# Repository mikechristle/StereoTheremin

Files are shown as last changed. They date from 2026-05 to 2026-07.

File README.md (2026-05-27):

# StereoTheremin
II'm sure you are familiar with the Theremin. 
It is a musical instrument that uses hand movements to control pitch and volume. 
One hand controls pitch, and the other hand control volume. 
I like the expressiveness of a no contact instrument,
 but controlling two variables is just too limiting. 
 With my version each hand controls both pitch and volume. 
 The up/down motion controls volume, and the right/left motion controls pitch. 
 This way the right hand plays treble and the left hand plays base, like a piano.
## Code
The micropython code that runs on the Raspberry PI Pico.
## Control
The python code that runs on a PC or a tablet to control the Stereo Theremin.
## PCB
The KiCad files for the printed circuit board. 
Version 10.0.

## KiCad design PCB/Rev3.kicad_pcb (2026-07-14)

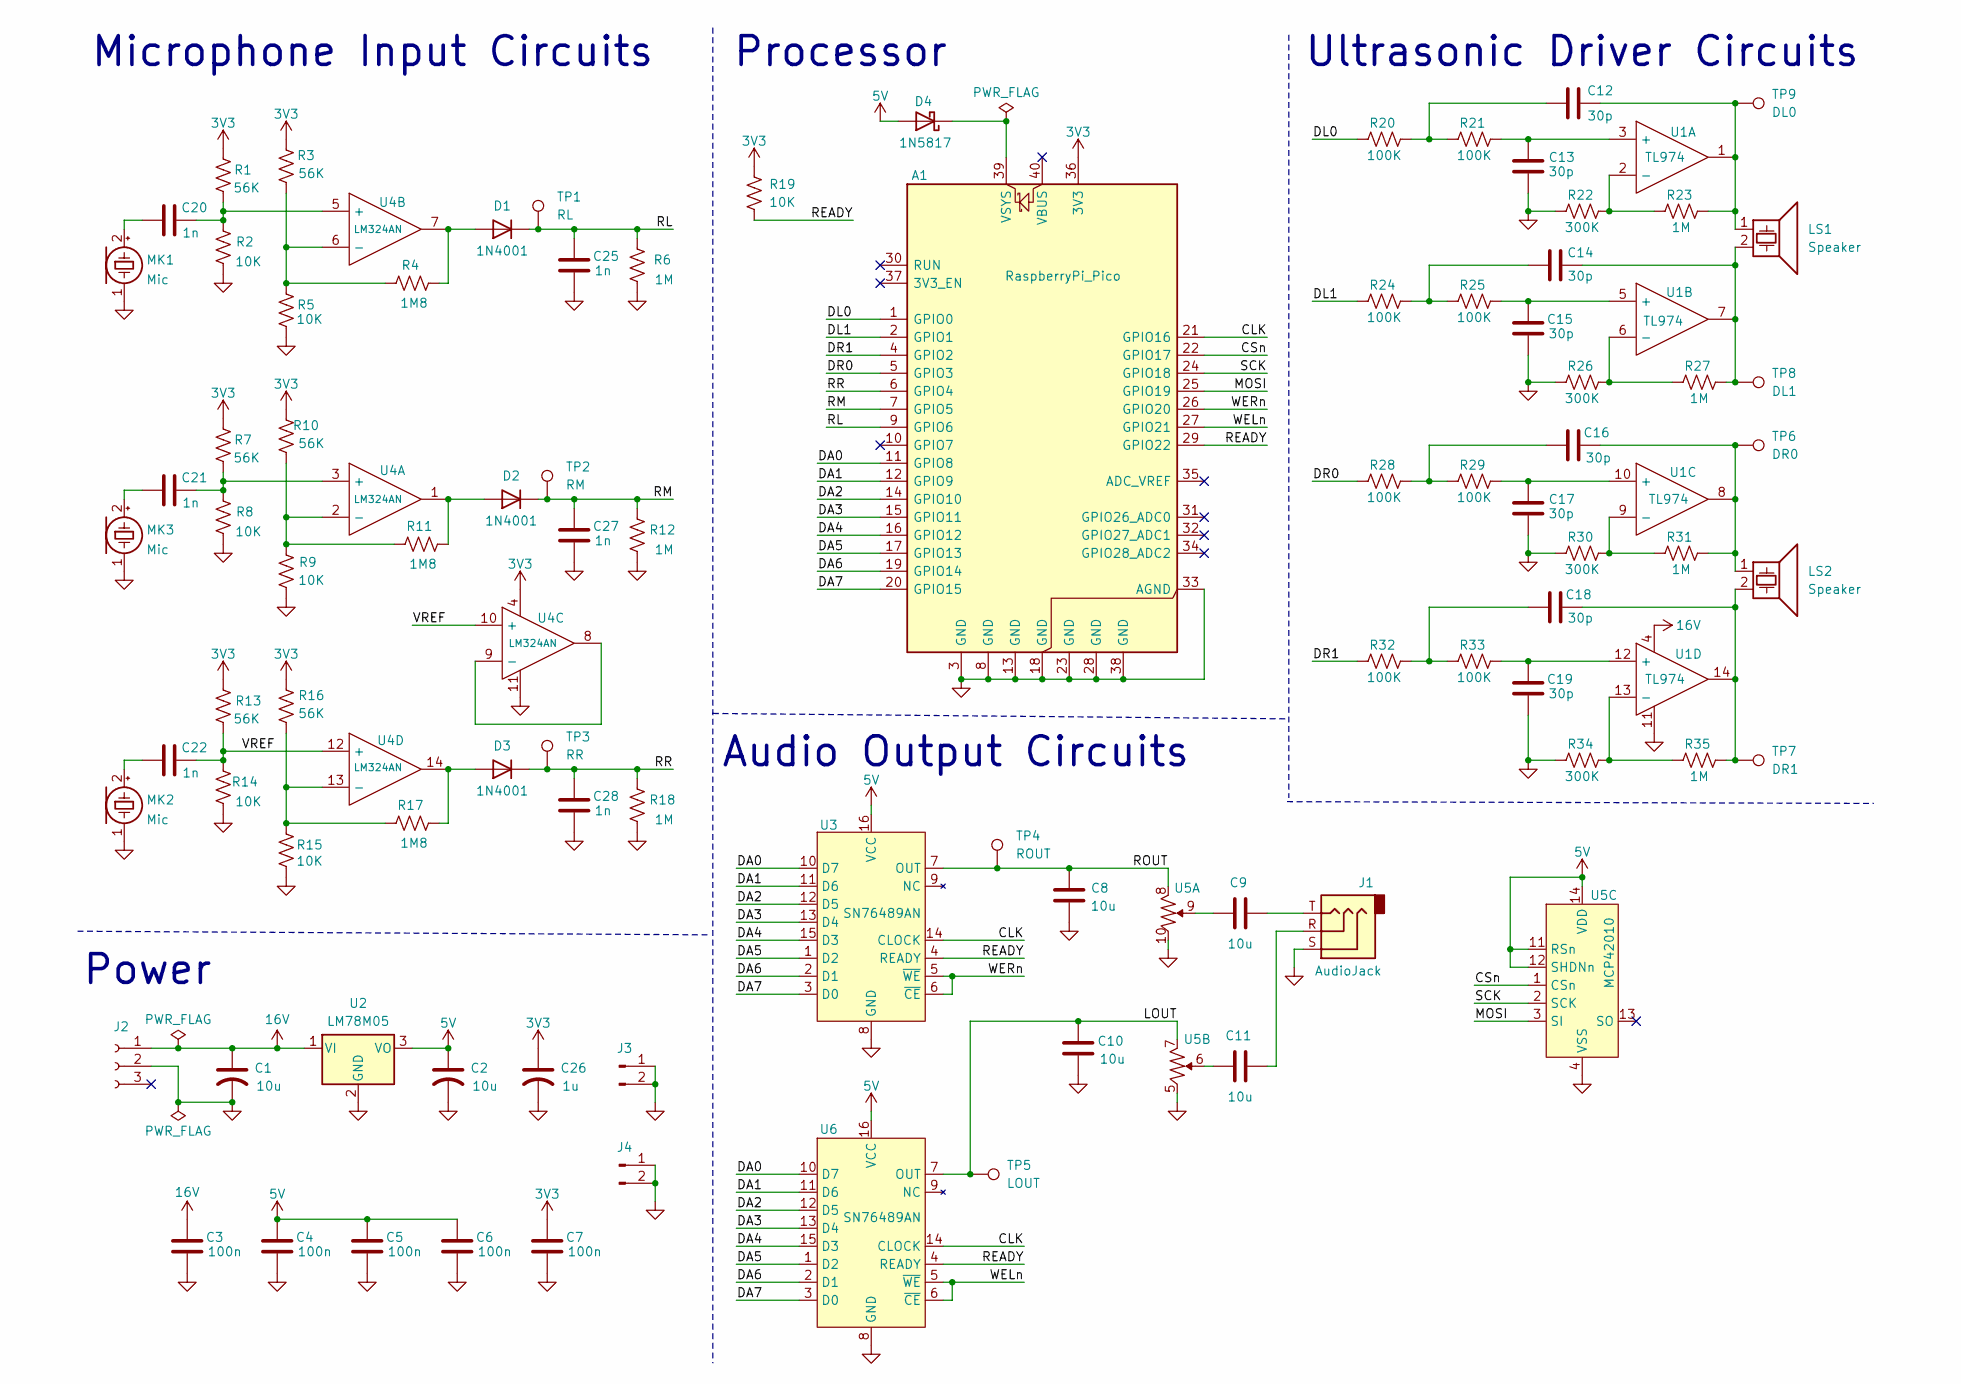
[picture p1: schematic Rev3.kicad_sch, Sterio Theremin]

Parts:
A1: RaspberryPi_Pico; RaspberryPi_Pico_Common_THT
C1, C2: 10u; CP_Radial_D6.3mm_P2.50mm
C3, C4, C5, C6, C7: 100n; C_Disc_D3.0mm_W1.6mm_P2.50mm
C8, C9, C10, C11: 10u; C_Disc_D4.3mm_W1.9mm_P5.00mm
C12, C13, C14, C15, C16, C17, C18, C19: 30p; C_Disc_D4.3mm_W1.9mm_P5.00mm
C20, C21, C22, C25, C27, C28: 1n; C_Disc_D4.3mm_W1.9mm_P5.00mm
C26: 1u; CP_Radial_D5.0mm_P2.50mm
D1, D2, D3: 1N4001; D_A-405_P7.62mm_Horizontal
D4: 1N5817; D_A-405_P7.62mm_Horizontal
J1: AudioJack; STX-3000
J2: Conn_01x03_Socket; BarrelJack_Kycon_KLDX-0202-xC_Horizontal
J3, J4: Conn_01x02_Pin; PinHeader_1x02_P2.54mm_Vertical
LS1, LS2: Speaker; Ultra Sonic TR
MK1, MK2, MK3: Mic; Ultra Sonic TR
R1, R3, R7, R10, R13, R16: 56K; R_Axial_DIN0204_L3.6mm_D1.6mm_P5.08mm_Horizontal
R2, R5, R8, R9, R14, R15, R19: 10K; R_Axial_DIN0204_L3.6mm_D1.6mm_P5.08mm_Horizontal
R4, R11, R17: 1M8; R_Axial_DIN0204_L3.6mm_D1.6mm_P5.08mm_Horizontal
R6, R12, R18, R23, R27, R31, R35: 1M; R_Axial_DIN0204_L3.6mm_D1.6mm_P5.08mm_Horizontal
R20, R21, R24, R25, R28, R29, R32, R33: 100K; R_Axial_DIN0204_L3.6mm_D1.6mm_P5.08mm_Horizontal
R22, R26, R30, R34: 300K; R_Axial_DIN0204_L3.6mm_D1.6mm_P5.08mm_Horizontal
TP1: RL; TestPoint_Loop_D2.50mm_Drill1.85mm
TP2: RM; TestPoint_Loop_D2.50mm_Drill1.85mm
TP3: RR; TestPoint_Loop_D2.50mm_Drill1.85mm
TP4: ROUT; TestPoint_Loop_D2.50mm_Drill1.85mm
TP5: LOUT; TestPoint_Loop_D2.50mm_Drill1.85mm
TP6: DR0; TestPoint_Loop_D2.50mm_Drill1.85mm
TP7: DR1; TestPoint_Loop_D2.50mm_Drill1.85mm
TP8: DL1; TestPoint_Loop_D2.50mm_Drill1.85mm
TP9: DL0; TestPoint_Loop_D2.50mm_Drill1.85mm
U1: TL974; DIP-14_W7.62mm
U2: LM78M05; TO-252-2
U3, U6: SN76489AN; DIP-16_W7.62mm
U4: LM324AN; DIP-14_W7.62mm
U5: MCP42010; DIP-14_W7.62mm

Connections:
3V3: A1.36 (3V3), C7.1, C26.1, R1.2, R3.2, R7.2, R10.2, R13.2, R16.2, R19.1, U4.4
5V: C2.1, C4.1, C5.1, C6.1, D4.2 (A), U2.3 (VO), U3.16 (VCC), U5.11 (RSn), U5.12 (SHDNn), U5.14 (VDD), U6.16 (VCC)
16V: C1.1, C3.1, J2.1, U1.4, U2.1 (VI)
/CLK: A1.21 (GPIO16), U3.14 (CLOCK), U6.14 (CLOCK)
/CSn: A1.22 (GPIO17), U5.1 (CSn)
/DA0: A1.11 (GPIO8), U3.10 (D7), U6.10 (D7)
/DA1: A1.12 (GPIO9), U3.11 (D6), U6.11 (D6)
/DA2: A1.14 (GPIO10), U3.12 (D5), U6.12 (D5)
/DA3: A1.15 (GPIO11), U3.13 (D4), U6.13 (D4)
/DA4: A1.16 (GPIO12), U3.15 (D3), U6.15 (D3)
/DA5: A1.17 (GPIO13), U3.1 (D2), U6.1 (D2)
/DA6: A1.19 (GPIO14), U3.2 (D1), U6.2 (D1)
/DA7: A1.20 (GPIO15), U3.3 (D0), U6.3 (D0)
/DL0: A1.1 (GPIO0), R20.1
/DL1: A1.2 (GPIO1), R24.1
/DR0: A1.5 (GPIO3), R28.1
/DR1: A1.4 (GPIO2), R32.1
/LOUT: C10.2, TP5.1 (1_1), U5.7, U6.7 (OUT)
/MOSI: A1.25 (GPIO19), U5.3 (SI)
/READY: A1.29 (GPIO22), R19.2, U3.4 (READY), U6.4 (READY)
/RL: A1.9 (GPIO6), C25.1, D1.1 (K), R6.2, TP1.1 (1_1)
/RM: A1.7 (GPIO5), C27.1, D2.1 (K), R12.2, TP2.1 (1_1)
/ROUT: C8.2, TP4.1 (1_1), U3.7 (OUT), U5.8
/RR: A1.6 (GPIO4), C28.1, D3.1 (K), R18.2, TP3.1 (1_1)
/SCK: A1.24 (GPIO18), U5.2 (SCK)
/VREF: C22.2, R13.1, R14.2, U4.10 (+), U4.12 (+)
/WELn: A1.27 (GPIO21), U6.5 (~WE), U6.6 (~CE)
/WERn: A1.26 (GPIO20), U3.5 (~WE), U3.6 (~CE)
GND: A1.3 (GND), A1.8 (GND), A1.13 (GND), A1.18 (GND), A1.23 (GND), A1.28 (GND), A1.33 (AGND), A1.38 (GND), C1.2, C2.2, C3.2, C4.2, C5.2, C6.2, C7.2, C8.1, C10.1, C13.2, C15.2, C17.2, C19.2, C25.2, C26.2, C27.2, C28.2, J1.S, J2.2, J3.1, J3.2, J4.1, J4.2, MK1.1 (-), MK2.1 (-), MK3.1 (-), R2.1, R5.2, R6.1, R8.1, R9.2, R12.1, R14.1, R15.2, R18.1, R22.1, R26.1, R30.1, R34.1, U1.11, U2.2 (GND), U3.8 (GND), U4.11, U5.4 (VSS), U5.5, U5.10, U6.8 (GND)
unnamed: A1.39 (VSYS), D4.1 (K)
unnamed: C9.1, J1.T
unnamed: C9.2, U5.9
unnamed: C11.1, J1.R
unnamed: C11.2, U5.6
unnamed: C12.1, R20.2, R21.1
unnamed: C12.2, LS1.1, R23.2, TP9.1 (1_1), U1.1
unnamed: C14.1, R24.2, R25.1
unnamed: C14.2, LS1.2, R27.2, TP8.1 (1_1), U1.7
unnamed: C16.1, R28.2, R29.1
unnamed: C16.2, LS2.1, R31.2, TP6.1 (1_1), U1.8
unnamed: C18.1, R32.2, R33.1
unnamed: C18.2, LS2.2, R35.2, TP7.1 (1_1), U1.14
unnamed: D1.2 (A), R4.2, U4.7
unnamed: D2.2 (A), R11.2, U4.1
unnamed: D3.2 (A), R17.2, U4.14
unnamed: C20.1, MK1.2 (+)
unnamed: C22.1, MK2.2 (+)
unnamed: C21.1, MK3.2 (+)
unnamed: C13.1, R21.2, U1.3 (+)
unnamed: R22.2, R23.1, U1.2 (-)
unnamed: C15.1, R25.2, U1.5 (+)
unnamed: R26.2, R27.1, U1.6 (-)
unnamed: C17.1, R29.2, U1.10 (+)
unnamed: R30.2, R31.1, U1.9 (-)
unnamed: C19.1, R33.2, U1.12 (+)
unnamed: R34.2, R35.1, U1.13 (-)
unnamed: C21.2, R7.1, R8.2, U4.3 (+)
unnamed: R9.1, R10.1, R11.1, U4.2 (-)
unnamed: C20.2, R1.1, R2.2, U4.5 (+)
unnamed: R3.1, R4.1, R5.1, U4.6 (-)
unnamed: U4.8, U4.9 (-)
unnamed: R15.1, R16.1, R17.1, U4.13 (-)

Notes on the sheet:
Audio Output Circuits
Processor
Power
Microphone Input Circuits
Ultrasonic Driver Circuits

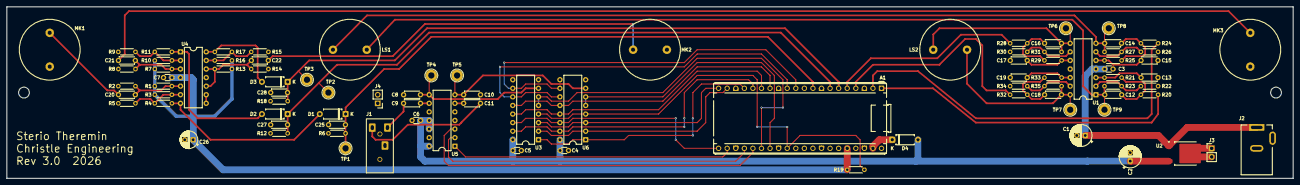
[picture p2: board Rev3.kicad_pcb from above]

Board: 2 copper layers, 381.0 x 50.8 mm, 90 parts (0 on the bottom side), 62 nets.

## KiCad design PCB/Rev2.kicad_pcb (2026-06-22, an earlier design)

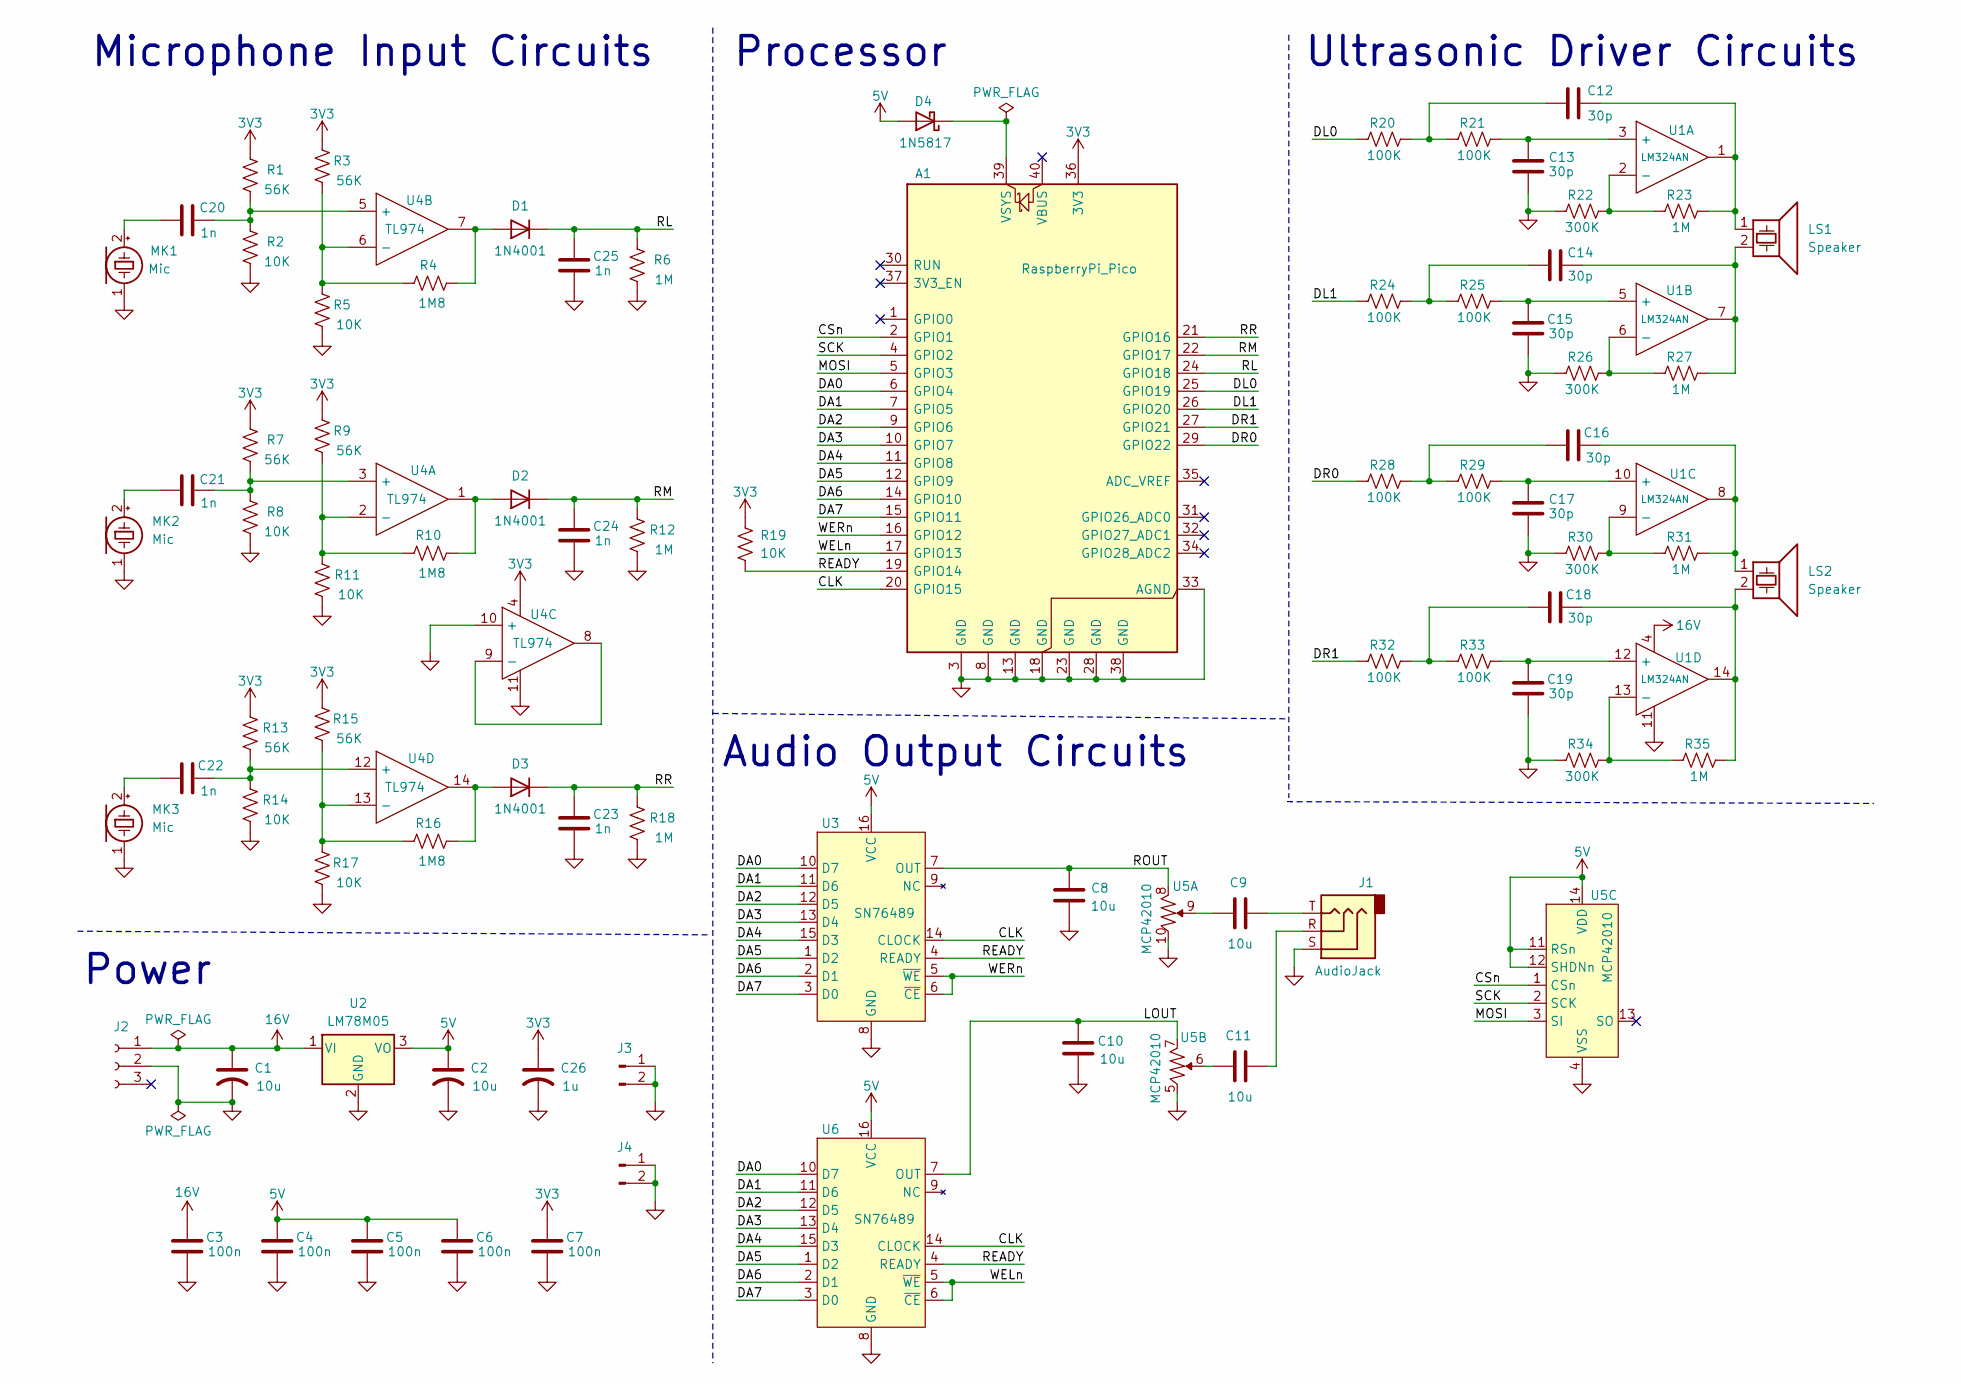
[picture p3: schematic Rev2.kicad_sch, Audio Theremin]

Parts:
A1: RaspberryPi_Pico; RaspberryPi_Pico_Common_THT
C1, C2: 10u; CP_Radial_D6.3mm_P2.50mm
C3, C4, C5, C6, C7: 100n; C_Disc_D3.0mm_W1.6mm_P2.50mm
C8, C9, C10, C11: 10u; C_Disc_D4.3mm_W1.9mm_P5.00mm
C12, C13, C14, C15, C16, C17, C18, C19: 30p; C_Disc_D4.3mm_W1.9mm_P5.00mm
C20, C21, C22, C23, C24, C25: 1n; C_Disc_D4.3mm_W1.9mm_P5.00mm
C26: 1u; CP_Radial_D5.0mm_P2.50mm
D1, D2, D3: 1N4001; D_DO-41_SOD81_P10.16mm_Horizontal
D4: 1N5817; D_DO-41_SOD81_P10.16mm_Horizontal
J1: AudioJack; STX-3000
J2: Conn_01x03_Socket; BarrelJack_Kycon_KLDX-0202-xC_Horizontal
J3, J4: Conn_01x02_Pin; PinHeader_1x02_P2.54mm_Vertical
LS1, LS2: Speaker; PinHeader_1x02_P2.54mm_Vertical
MK1, MK2, MK3: Mic; PinHeader_1x02_P2.54mm_Vertical
R1, R3, R7, R9, R13, R15: 56K; R_Axial_DIN0204_L3.6mm_D1.6mm_P5.08mm_Horizontal
R2, R5, R8, R11, R14, R17, R19: 10K; R_Axial_DIN0204_L3.6mm_D1.6mm_P5.08mm_Horizontal
R4, R10, R16: 1M8; R_Axial_DIN0204_L3.6mm_D1.6mm_P5.08mm_Horizontal
R6, R12, R18, R23, R27, R31, R35: 1M; R_Axial_DIN0204_L3.6mm_D1.6mm_P5.08mm_Horizontal
R20, R21, R24, R25, R28, R29, R32, R33: 100K; R_Axial_DIN0204_L3.6mm_D1.6mm_P5.08mm_Horizontal
R22, R26, R30, R34: 300K; R_Axial_DIN0204_L3.6mm_D1.6mm_P5.08mm_Horizontal
U1: LM324AN; DIP-14_W7.62mm
U2: LM78M05; TO-252-2
U3, U6: SN76489; DIP-16_W7.62mm
U4: TL974; DIP-14_W7.62mm
U5: MCP42010; DIP-14_W7.62mm

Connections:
3V3: A1.36 (3V3), C7.1, C26.1, R1.2, R3.2, R7.2, R9.2, R13.2, R15.2, R19.1, U4.4
5V: C2.1, C4.1, C5.1, C6.1, D4.2 (A), U2.3 (VO), U3.16 (VCC), U5.11 (RSn), U5.12 (SHDNn), U5.14 (VDD), U6.16 (VCC)
16V: C1.1, C3.1, J2.1, U1.4, U2.1 (VI)
/CLK: A1.20 (GPIO15), U3.14 (CLOCK), U6.14 (CLOCK)
/CSn: A1.2 (GPIO1), U5.1 (CSn)
/DA0: A1.6 (GPIO4), U3.10 (D7), U6.10 (D7)
/DA1: A1.7 (GPIO5), U3.11 (D6), U6.11 (D6)
/DA2: A1.9 (GPIO6), U3.12 (D5), U6.12 (D5)
/DA3: A1.10 (GPIO7), U3.13 (D4), U6.13 (D4)
/DA4: A1.11 (GPIO8), U3.15 (D3), U6.15 (D3)
/DA5: A1.12 (GPIO9), U3.1 (D2), U6.1 (D2)
/DA6: A1.14 (GPIO10), U3.2 (D1), U6.2 (D1)
/DA7: A1.15 (GPIO11), U3.3 (D0), U6.3 (D0)
/DL0: A1.25 (GPIO19), R20.1
/DL1: A1.26 (GPIO20), R24.1
/DR0: A1.29 (GPIO22), R28.1
/DR1: A1.27 (GPIO21), R32.1
/LOUT: C10.2, U5.7, U6.7 (OUT)
/MOSI: A1.5 (GPIO3), U5.3 (SI)
/READY: A1.19 (GPIO14), R19.2, U3.4 (READY), U6.4 (READY)
/RL: A1.24 (GPIO18), C25.1, D1.1 (K), R6.2
/RM: A1.22 (GPIO17), C24.1, D2.1 (K), R12.2
/ROUT: C8.2, U3.7 (OUT), U5.8
/RR: A1.21 (GPIO16), C23.1, D3.1 (K), R18.2
/SCK: A1.4 (GPIO2), U5.2 (SCK)
/WELn: A1.17 (GPIO13), U6.5 (~WE), U6.6 (~CE)
/WERn: A1.16 (GPIO12), U3.5 (~WE), U3.6 (~CE)
GND: A1.3 (GND), A1.8 (GND), A1.13 (GND), A1.18 (GND), A1.23 (GND), A1.28 (GND), A1.33 (AGND), A1.38 (GND), C1.2, C2.2, C3.2, C4.2, C5.2, C6.2, C7.2, C8.1, C10.1, C13.2, C15.2, C17.2, C19.2, C23.2, C24.2, C25.2, C26.2, J1.S, J2.2, J3.1, J3.2, J4.1, J4.2, MK1.1 (-), MK2.1 (-), MK3.1 (-), R2.1, R5.1, R6.1, R8.1, R11.1, R12.1, R14.1, R17.1, R18.1, R22.1, R26.1, R30.1, R34.1, U1.11, U2.2 (GND), U3.8 (GND), U4.10 (+), U4.11, U5.4 (VSS), U5.5, U5.10, U6.8 (GND)
unnamed: A1.39 (VSYS), D4.1 (K)
unnamed: C9.1, J1.T
unnamed: C9.2, U5.9
unnamed: C11.1, J1.R
unnamed: C11.2, U5.6
unnamed: C12.1, R20.2, R21.1
unnamed: C12.2, LS1.1, R23.2, U1.1
unnamed: C14.1, R24.2, R25.1
unnamed: C14.2, LS1.2, R27.2, U1.7
unnamed: C16.1, R28.2, R29.1
unnamed: C16.2, LS2.1, R31.2, U1.8
unnamed: C18.1, R32.2, R33.1
unnamed: C18.2, LS2.2, R35.2, U1.14
unnamed: D1.2 (A), R4.2, U4.7
unnamed: D2.2 (A), R10.2, U4.1
unnamed: D3.2 (A), R16.2, U4.14
unnamed: C20.1, MK1.2 (+)
unnamed: C21.1, MK2.2 (+)
unnamed: C22.1, MK3.2 (+)
unnamed: C13.1, R21.2, U1.3 (+)
unnamed: R22.2, R23.1, U1.2 (-)
unnamed: C15.1, R25.2, U1.5 (+)
unnamed: R26.2, R27.1, U1.6 (-)
unnamed: C17.1, R29.2, U1.10 (+)
unnamed: R30.2, R31.1, U1.9 (-)
unnamed: C19.1, R33.2, U1.12 (+)
unnamed: R34.2, R35.1, U1.13 (-)
unnamed: C21.2, R7.1, R8.2, U4.3 (+)
unnamed: R9.1, R10.1, R11.2, U4.2 (-)
unnamed: C20.2, R1.1, R2.2, U4.5 (+)
unnamed: R3.1, R4.1, R5.2, U4.6 (-)
unnamed: U4.8, U4.9 (-)
unnamed: C22.2, R13.1, R14.2, U4.12 (+)
unnamed: R15.1, R16.1, R17.2, U4.13 (-)

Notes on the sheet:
Audio Output Circuits
Processor
Power
Microphone Input Circuits
Ultrasonic Driver Circuits

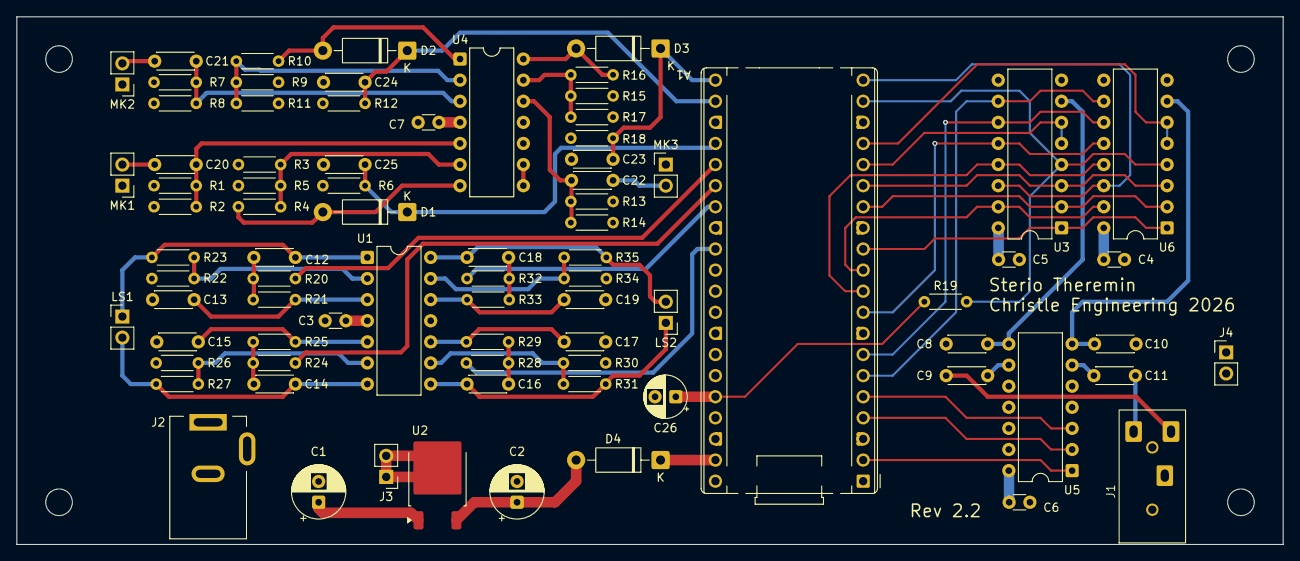
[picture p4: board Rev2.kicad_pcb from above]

Board: 4 copper layers, 152.4 x 63.5 mm, 85 parts (0 on the bottom side), 62 nets.

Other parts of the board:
MH1, MH2, MH3, MH4: MountingHole_3.2mm_M3

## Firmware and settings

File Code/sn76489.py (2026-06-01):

# -------------------------------------------------------------------------
# SN76489 Sound Generator PIO Code
# Mike Christle 2026
#
# Pin order:
# D0, D1, D2, D3, D4, D5, D6, D7, WER, WEL, READY, CLK
# -------------------------------------------------------------------------
from machine import Pin, PWM
import rp2


CLK_FREQ = 654_720


class SN76489:
    def __init__(self, smn, pin):
        '''
        Driver for the SN76489 audio generator chips.
        smn    State machine number.
        pin    GPIO number of the first pin.
        '''
        self.d7 = Pin(pin,     Pin.OUT)
        self.d6 = Pin(pin + 1, Pin.OUT)
        self.d5 = Pin(pin + 2, Pin.OUT)
        self.d4 = Pin(pin + 3, Pin.OUT)
        self.d3 = Pin(pin + 4, Pin.OUT)
        self.d2 = Pin(pin + 5, Pin.OUT)
        self.d1 = Pin(pin + 6, Pin.OUT)
        self.d0 = Pin(pin + 7, Pin.OUT)

        self.wel = Pin(pin +  8, Pin.OUT, value=1) # WEn & CEn
        self.wer = Pin(pin +  9, Pin.OUT, value=1) # WEn & CEn
        self.rdy = Pin(pin + 10, Pin.IN)

        self.clk = Pin(pin + 11, Pin.OUT)
        self.clk_pwm = PWM(self.clk,
                           freq=CLK_FREQ,
                           duty_u16=32_768)
#         freq = self.clk_pwm.freq()
#         print(freq)

        self.sm = rp2.StateMachine(
            smn,
            self.sm_code,
            freq=10_000_000,
            out_base=self.d7,
            set_base=self.wel,
            jmp_pin=self.rdy,
            )
        self.sm.active(1)

        # Turn off all outputs
        self.write_reg(0, 1, 0x0F)
        self.write_reg(0, 3, 0x0F)
        self.write_reg(0, 5, 0x0F)
        self.write_reg(0, 7, 0x0F)
        self.write_reg(1, 1, 0x0F)
        self.write_reg(1, 3, 0x0F)
        self.write_reg(1, 5, 0x0F)
        self.write_reg(1, 7, 0x0F)

        self.factors = [[0.0, 0.0], [0.0, 0.0]]
        self.attens = [[15, 15], [15, 15]]

    # ---------------------------------------------------------------------
    def set_factor(self, chip, chan, data):
        '''
        Set the frequency factor for a voice.
        chip    Chip number, 0 or 1.
        chan    Channel number, 2 or 3.
        data    Factor value.
        '''

        if chip < 0 or chip > 1:
            raise ValueError('Chip out of range, 0, 1.')

        if chan < 2 or chan > 3:
            raise ValueError('Channel number out of range, 2 or 3.')

        
        self.factors[chip][chan - 2] = data

    # ---------------------------------------------------------------------
    def set_atten(self, chip, chan, data):
        '''
        Set the attenuation for a voice.
        chip    Chip number, 0 or 1.
        chan    Channel number, 2 or 3.
        data    Attenuation value.
        '''

        if chip < 0 or chip > 1:
            raise ValueError('Chip out of range, 0, 1.')

        if chan < 2 or chan > 3:
            raise ValueError('Channel number out of range, 2 or 3.')

        
        self.attens[chip][chan - 2] = data

    # ---------------------------------------------------------------------
    def write_reg(self, chip, adrs, data):
        '''
        Write value to a register.
        chip    Chip number, 0 or 1.
        adrs    Address to write, 0 to 7.
        data    Data value.
        '''

        value = (chip << 8) | 0x80 | (adrs << 4) | (data & 0x0F)
        # print(f'value 1 {value:08X}')
        self.sm.put(value)
        if adrs == 0 or adrs == 2 or adrs == 4:
            value = (chip << 8) | (data >> 4)
            # print(f'value 2 {value:08X}')
            self.sm.put(value)

    # ---------------------------------------------------------------------
    def write_freq(self, chip, chan, freq):
        '''
        chip   Chip to write.     0, 1
        chan   Channel to write.  0, 1, 2
        freq   Frequency.         20 to 20K Hz
               
        '''

        if chip < 0 or chip > 1:
            raise ValueError('Chip out of range, 0, 1.')

        if chan < 0 or chan > 2:
            raise ValueError('Channel out of range, 0, 1, 2.')

        if freq < 20 or freq > 20_000:
            raise ValueError('Frequency out of range, 20 to 20K Hz.')

        freq = int(CLK_FREQ / 32 / freq)
        adrs = chan * 2
        self.write_reg(chip, adrs, freq)

    # ---------------------------------------------------------------------
    def write_attn(self, chip, chan, attn):
        '''
        chip   Chip to write.     0, 1
        chan   Channel to write.  0, 1, 2
        attn   Attenuation.       0 to 30 db in 2db increments
               
        '''

        if chip < 0 or chip > 1:
            raise ValueError('Chip out of range, 0, 1.')

        if chan < 0 or chan > 2:
            raise ValueError('Channel out of range, 0, 1, 2.')

        if attn < 0 or attn > 30:
            raise ValueError('Attenuation out of range, 0 to 30 db.')

        attn //= 2
        adrs = chan * 2
        self.write_reg(chip, adrs + 1, attn)

    # ---------------------------------------------------------------------
    def update(chip, freq):
        '''
        Update the frequency and attenuation for a channel.
        chip    Chip number, 0 or 1.
        freq    Frequency for voice 1.
        '''

        write_freq(chip, 0, freq)
        write_freq(chip, 1, freq * self.factor[chip][0])
        write_freq(chip, 2, freq * self.factor[chip][1])

        write_attn(chip, 1, self.factor[chip][0])
        write_attn(chip, 2, self.factor[chip][1])

    # ---------------------------------------------------------------------
    @rp2.asm_pio(out_shiftdir=rp2.PIO.SHIFT_RIGHT,
                 fifo_join=rp2.PIO.JOIN_TX,
                 set_init=(rp2.PIO.OUT_HIGH, rp2.PIO.OUT_HIGH),
                 out_init=(rp2.PIO.OUT_LOW, rp2.PIO.OUT_LOW,
                           rp2.PIO.OUT_LOW, rp2.PIO.OUT_LOW,
                           rp2.PIO.OUT_LOW, rp2.PIO.OUT_LOW,
                           rp2.PIO.OUT_LOW, rp2.PIO.OUT_LOW))
    def sm_code():

        label('lbl0')
        set(pins, 3)        # Clear WE
        pull(block)         # Wait for nect command
        out(pins, 8)        # Output data byte
        out(y, 24)          # Which channel?
        jmp(not_y, 'lbl1')

        set(pins, 1)        # Assert WERn
        jmp('lbl2')

        label('lbl1')
        set(pins, 2) [1]    # Assert WELn

        label('lbl2')
        jmp(pin, 'lbl0')    # Wait for READY to go high
        jmp('lbl2')


# -------------------------------------------------------------------------
C0  = 7645  # 16.35 Hz
C0S = 7217  # 17.32 Hz
D0  = 6812  # 18.35 Hz
D0S = 6427  # 19.45 Hz
E0  = 6068  # 20.6 Hz
F0  = 5726  # 21.83 Hz
F0S = 5407  # 23.12 Hz
G0  = 5102  # 24.5 Hz
G0S = 4815  # 25.96 Hz
A0  = 4545  # 27.5 Hz
A0S = 4290  # 29.14 Hz
B0  = 4049  # 30.87 Hz
C1  = 3823  # 32.7 Hz
C1S = 3608  # 34.65 Hz
D1  = 3405  # 36.71 Hz
D1S = 3214  # 38.89 Hz
E1  = 3034  # 41.2 Hz
F1  = 2864  # 43.65 Hz
F1S = 2703  # 46.25 Hz
G1  = 2551  # 49.0 Hz
G1S = 2408  # 51.91 Hz
A1  = 2273  # 55.0 Hz
A1S = 2145  # 58.27 Hz
B1  = 2025  # 61.74 Hz
C2  = 1911  # 65.41 Hz
C2S = 1804  # 69.3 Hz
D2  = 1703  # 73.42 Hz
D2S = 1607  # 77.78 Hz
E2  = 1517  # 82.41 Hz
F2  = 1432  # 87.31 Hz
F2S = 1351  # 92.5 Hz
G2  = 1276  # 98.0 Hz
G2S = 1204  # 103.83 Hz
A2  = 1136  # 110.0 Hz
A2S = 1073  # 116.54 Hz
B2  = 1012  # 123.47 Hz
C3  =  956  # 130.81 Hz
C3S =  902  # 138.59 Hz
D3  =  851  # 146.83 Hz
D3S =  804  # 155.56 Hz
E3  =  758  # 164.81 Hz
F3  =  716  # 174.61 Hz
F3S =  676  # 185.0 Hz
G3  =  638  # 196.0 Hz
G3S =  602  # 207.65 Hz
A3  =  568  # 220.0 Hz
A3S =  536  # 233.08 Hz
B3  =  506  # 246.94 Hz
C4  =  478  # 261.63 Hz
C4S =  451  # 277.18 Hz
D4  =  426  # 293.66 Hz
D4S =  402  # 311.13 Hz
E4  =  379  # 329.63 Hz
F4  =  358  # 349.23 Hz
F4S =  338  # 369.99 Hz
G4  =  319  # 392.0 Hz
G4S =  301  # 415.3 Hz
A4  =  284  # 440.0 Hz
A4S =  268  # 466.16 Hz
B4  =  253  # 493.88 Hz
C5  =  239  # 523.25 Hz
C5S =  225  # 554.37 Hz
D5  =  213  # 587.33 Hz
D5S =  201  # 622.25 Hz
E5  =  190  # 659.26 Hz
F5  =  179  # 698.46 Hz
F5S =  169  # 739.99 Hz
G5  =  159  # 783.99 Hz
G5S =  150  # 830.61 Hz
A5  =  142  # 880.0 Hz
A5S =  134  # 932.33 Hz
B5  =  127  # 987.77 Hz
C6  =  119  # 1046.5 Hz
C6S =  113  # 1108.73 Hz
D6  =  106  # 1174.66 Hz
D6S =  100  # 1244.51 Hz
E6  =   95  # 1318.51 Hz
F6  =   89  # 1396.91 Hz
F6S =   84  # 1479.98 Hz
G6  =   80  # 1567.98 Hz
G6S =   75  # 1661.22 Hz
A6  =   71  # 1760.0 Hz
A6S =   67  # 1864.66 Hz
B6  =   63  # 1975.53 Hz
C7  =   60  # 2093.0 Hz
C7S =   56  # 2217.46 Hz
D7  =   53  # 2349.32 Hz
D7S =   50  # 2489.02 Hz
E7  =   47  # 2637.02 Hz
F7  =   45  # 2793.83 Hz
F7S =   42  # 2959.96 Hz
G7  =   40  # 3135.96 Hz
G7S =   38  # 3322.44 Hz
A7  =   36  # 3520.0 Hz
A7S =   34  # 3729.31 Hz
B7  =   32  # 3951.07 Hz
C8  =   30  # 4186.01 Hz
C8S =   28  # 4434.92 Hz
D8  =   27  # 4698.64 Hz
D8S =   25  # 4978.03 Hz

# -------------------------------------------------------------------------
if __name__ == "__main__":

    from time import sleep

    MENU = (
    'x         Exit\n'
    'f n c v   Set chip n channel c to frequency v\n'
    'a n c v   Set chip n channel c to attenuation v\n'
    )

    sn = SN76489(0, 0)
    print(MENU)
    while True:
        cmd = input('> ').split()
        cnt = len(cmd)
        if cnt < 1:
            print(MENU)
        elif cmd[0] == 'x':
            break
        elif cnt != 4:
            continue
        elif cmd[0] == 'f':
            chip = int(cmd[1])
            chan = int(cmd[2])
            freq = int(cmd[3])
            sn.write_freq(chip, chan, freq)
        elif cmd[0] == 'a':
            chip = int(cmd[1])
            chan = int(cmd[2])
            attn = int(cmd[3])
            sn.write_attn(chip, chan, attn)

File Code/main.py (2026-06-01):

# -------------------------------------------------------------------------
# Ultrasonic Theremin
# Mike Christle Feb 2026
# -------------------------------------------------------------------------

from machine import Pin, SPI
from mcp42010 import MCP42010
from sn76489 import SN76489
from sequencer import Sequencer
from measure import Measure
from machine import reset


LEFT_FREQ_LO = 65.41
LEFT_FREQ_HI = 493.88
RIGHT_FREQ_LO = 130.81
RIGHT_FREQ_HI = 987.77


cntr = 0
# -------------------------------------------------------------------------
def process_left(_):
    global cntr

    ll = mll.get()
    lm = mlm.get()
    if trace_left:
        print(f'process_left {ll} {lm} {cntr}   \r', end='')
        cntr += 1

    if ll or lm < 0:
        return

    left_pitch = lm - ll
    left_volume = lm + ll
    pots.write(MCP42010.POT0, left_volume)


# -------------------------------------------------------------------------
def process_right(_):
    global cntr

    rm = mrm.get()
    rr = mrr.get()
    if trace_right:
        print(f'process_right {rm} {rr} {cntr}   \r', end='')
        cntr += 1

    if rm or rr < 0:
        return

    right_pitch = rr - rm
    right_volume = rr + rm
    pots.write(MCP42010.POT1, right_volume)


# -------------------------------------------------------------------------
# Setup pins
pin_dl0 = Pin(19, mode=Pin.OUT)
pin_dl1 = Pin(20, mode=Pin.OUT)
pin_dr0 = Pin(21, mode=Pin.OUT)
pin_dr1 = Pin(22, mode=Pin.OUT)

pin_rl = Pin(18, mode=Pin.IN)
pin_rm = Pin(17, mode=Pin.IN)
pin_rr = Pin(16, mode=Pin.IN)

# spi, cs_pin, clk_pin, tx_pin
pots = MCP42010(0, 1, 2, 3)

# smn, first_pin
audio = SN76489(7, 4)

# smn, tx_pin, rx_pin
mll = Measure(2, pin_dl0, pin_rl)
mlm = Measure(3, pin_dl0, pin_rm)
mrm = Measure(5, pin_dr0, pin_rm)
mrr = Measure(6, pin_dr0, pin_rr)

# right_cb, left_cb, pins
pins = 19, 18, 17, 16
seq = Sequencer(process_right, process_left, pin_dl0)

trace_left = False
trace_right = True

FACTORS = [
    1.0,          # P1
    1.0 + 1/12,   # m2
    1.0 + 2/12,   # M2
    1.0 + 3/12,   # m3
    1.0 + 4/12,   # M3
    1.0 + 5/12,   # P4
    1.0 + 6/12,   # a4
    1.0 + 7/12,   # P5
    1.0 + 8/12,   # m6
    1.0 + 9/12,   # M6
    1.0 + 10/12,  # m7
    1.0 + 11/12,  # M7
    2.0,          # P8
    2.0,          # 2X
    3.0,          # 3X
    4.0,          # 4X
    5.0,          # 5X
    6.0,          # 6X
    7.0,          # 7X
    8.0,          # 8X
    9.0,          # 9X
    ]


MENU = '''
x       Exit
tl      Enable trace mode for left side.
tr      Enable trace mode for right side.

L2F N   Set left voice 2 to frequency N.
L2A N   Set left voice 2 to attenuation N. 
L3F N   Set left voice 3 to frequency N.
L3A N   Set left voice 2 to attenuation N. 

R2F N   Set right voice 2 to frequency N.
R2A N   Set right voice 2 to attenuation N. 
R3F N   Set right voice 3 to frequency N.
R3A N   Set right voice 3 to attenuation N. 
'''

while True:
    cmd = input('= ').split()
    cnt = len(cmd)

    if cnt == 0:
        print(MENU)
        continue
    if cmd[0] == 'x':
        break
    if cmd[0] == 'tl':
        trace_left = True
        input('Press return to stop\n')
        trace_left = False
        print()
    if cmd[0] == 'tr':
        trace_right = True
        input('Press return to stop\n')
        trace_right = False
        print()
    if cnt == 1:
        continue

    val = int(cmd[1])
    if cmd[0] == 'L2F':
        audio.set_factor(0, 2, FACTORS[val])
    if cmd[0] == 'L3F':
        audio.set_factor(0, 3, FACTORS[val])
    if cmd[0] == 'R2F':
        audio.set_factor(1, 2, FACTORS[val])
    if cmd[0] == 'R3F':
        audio.set_factor(1, 3, FACTORS[val])

    if cmd[0] == 'L2V':
        audio.set_atten(0, 2, val)
    if cmd[0] == 'L3V':
        audio.set_atten(0, 3, val)
    if cmd[0] == 'R2V':
        audio.set_atten(1, 2, val)
    if cmd[0] == 'R3V':
        audio.set_atten(1, 3, val)

reset()

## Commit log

2026-05-27 Initial release
    [Rev2.kicad_pcb, Rev2.kicad_sch]
2026-06-09 Doubled gain on receiver circuits.
    [Rev2.kicad_sch]
2026-06-22 Add files via upload
    Changed default output voltage on receiver circuit. Added ground points, J4.
    [Rev2.kicad_pcb, Rev2.kicad_sch]
2026-07-14 Add files via upload
    Initial release.
    [Rev3.kicad_pcb, Rev3.kicad_sch]
